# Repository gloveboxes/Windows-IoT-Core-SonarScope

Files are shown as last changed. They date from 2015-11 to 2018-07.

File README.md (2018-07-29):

# Windows-IoT-Core-SonarScope

Original Project Inspiration [Windows 10 IoT Core: UltraSonic Distance Mapper](https://microsoft.hackster.io/en-US/AnuragVasanwala/windows-10-iot-core-ultrasonic-distance-mapper-d94d63)

This project has had a lot of love, optimisation and polish espically around XAML with special fade effects and object clean up.

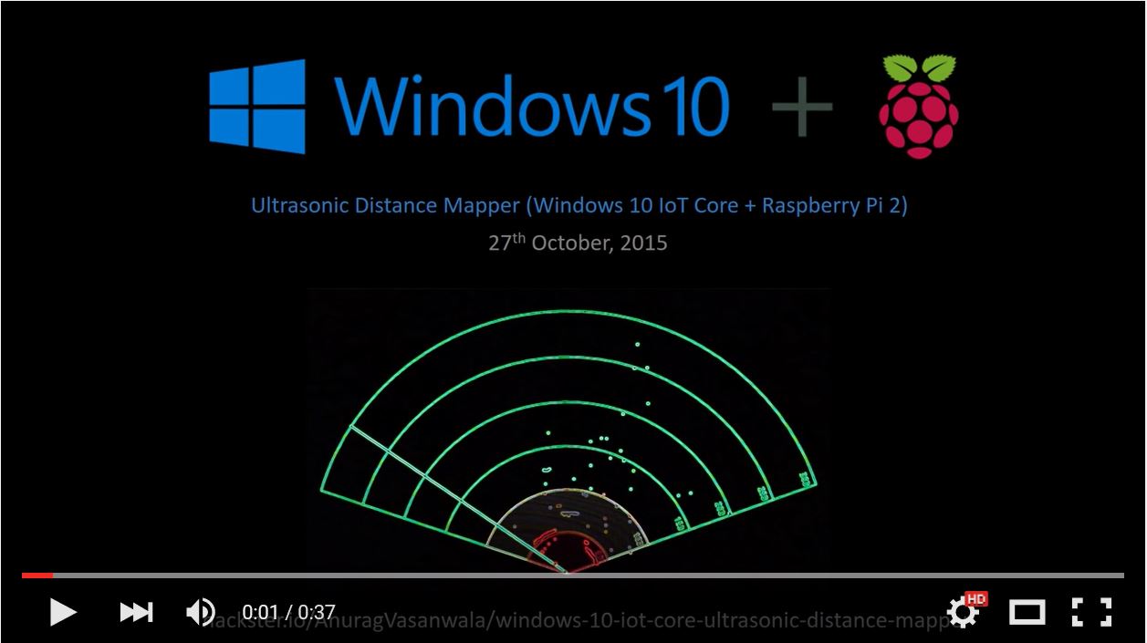
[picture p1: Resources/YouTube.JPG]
Youtube (https://youtu.be/GKRDX3nHlks)


<iframe width="420" height="315" src="https://www.youtube.com/embed/GKRDX3nHlks" frameborder="0" allowfullscreen></iframe>

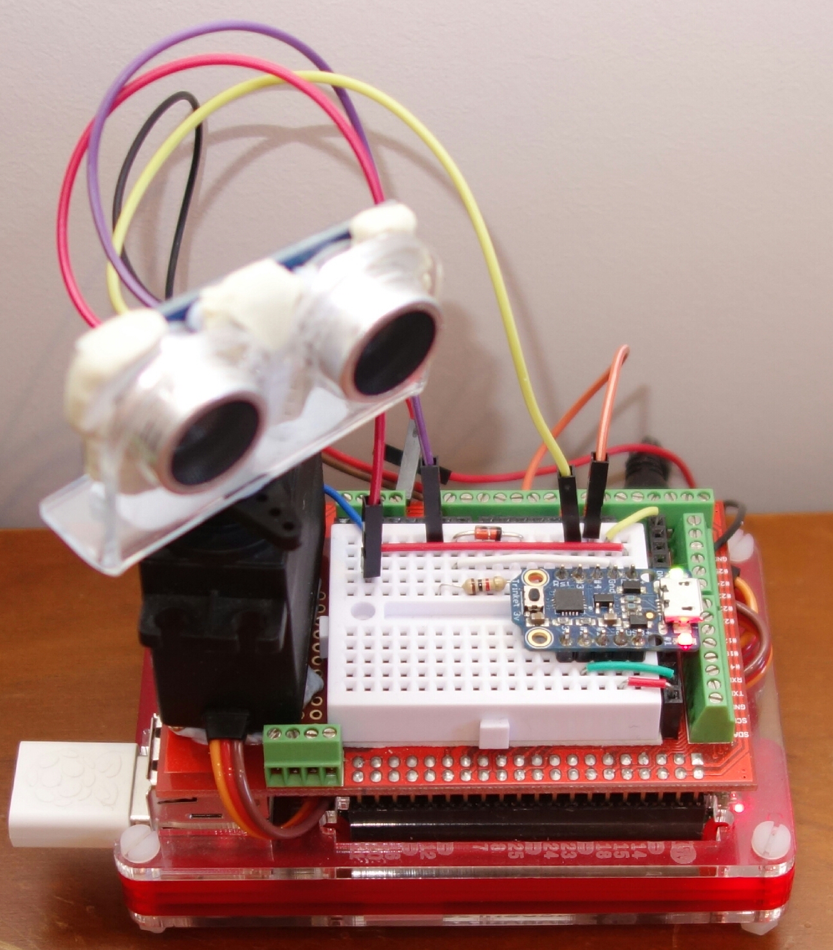
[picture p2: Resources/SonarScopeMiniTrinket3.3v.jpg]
Sonar Scope


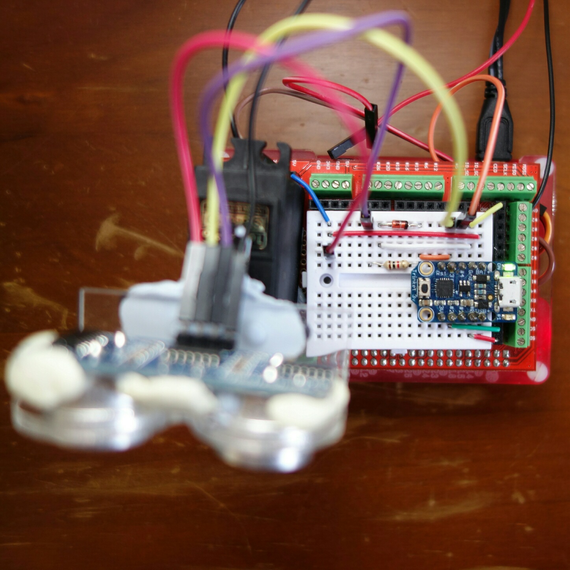
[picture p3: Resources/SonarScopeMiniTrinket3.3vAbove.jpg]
Sonar Scope


This project drives the servo over I2C bus from Windows IoT Core to Trinket Mini 3.3V Arduino board.

[Trinket Mini 3.3V](https://www.adafruit.com/products/1500) as it operates at the same voltage as the Raspberry Pi no logic level shifter required.

## Parts List

1. Raspberry Pi 2 or 3
2. [Adafruit Trinket - Mini Microcontroller - 3.3V Logic - MicroUSB](https://www.adafruit.com/products/1500)
3. [Zenor Diode 3.3v 1N4728A](http://au.rs-online.com/web/p/zener-diodes/8050034/)
4. 1K ohm resistor
5. 1 x Servo. I used a [Tower Pro SG-5010](https://www.adafruit.com/product/155)
6. HC-SR04 ultrasonic sensor. Widely avaiable sensor
7. [Servo Power Connector](https://www.jaycar.com.au/2-1mm-dc-socket-with-screw-terminals/p/PA3713)

## Powering the Servo

Ideally you should power the servo from its own separate power supply. However, given the servo is under very light load and if you are careful not to stall the servo you will likely get away with powering the servo from the 5v pin on the Raspberry Pi.

### Notes

1. A lightly loaded servo will draw around 200 milliamps
2. [Max current that can be supplied by 5V pin](http://raspberrypi.stackexchange.com/questions/42630/is-there-a-max-current-that-can-be-supplied-when-powering-the-pi-from-the-pins)

## Wiring

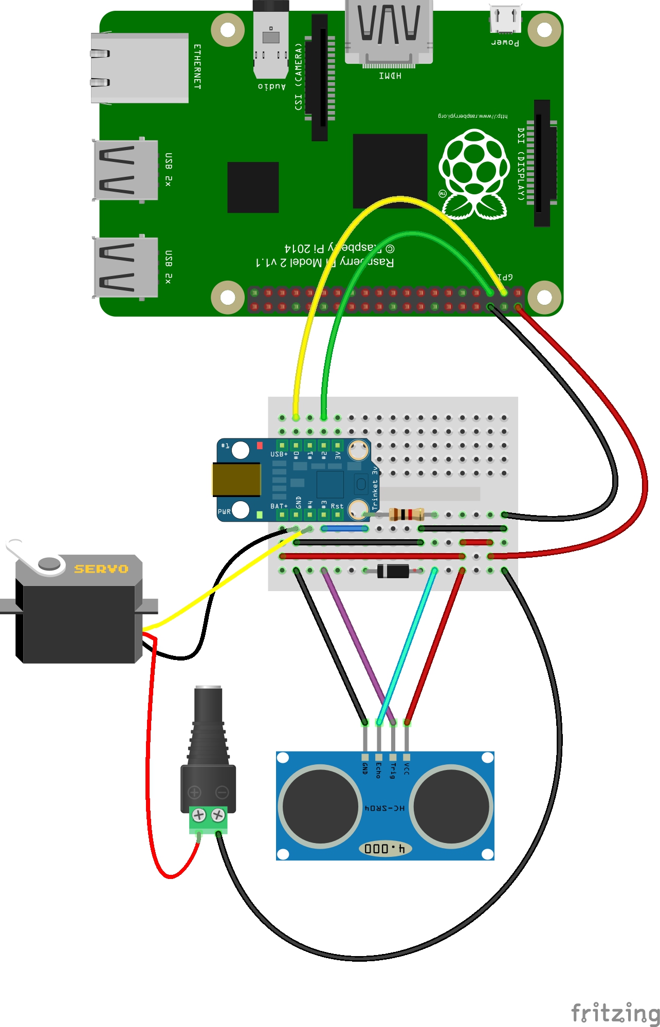
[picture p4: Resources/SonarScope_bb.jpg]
layout


## Alternate wiring for ATtiny85

I ended up swapping out the Adafruit Trinket for a ATtiny85 microcontroller. It's wired up as follows. I used an Arduino Uno to program the ATtiny85 as per these [instructions](https://www.instructables.com/id/Program-an-ATtiny-with-Arduino/). Worked very well and very fast.

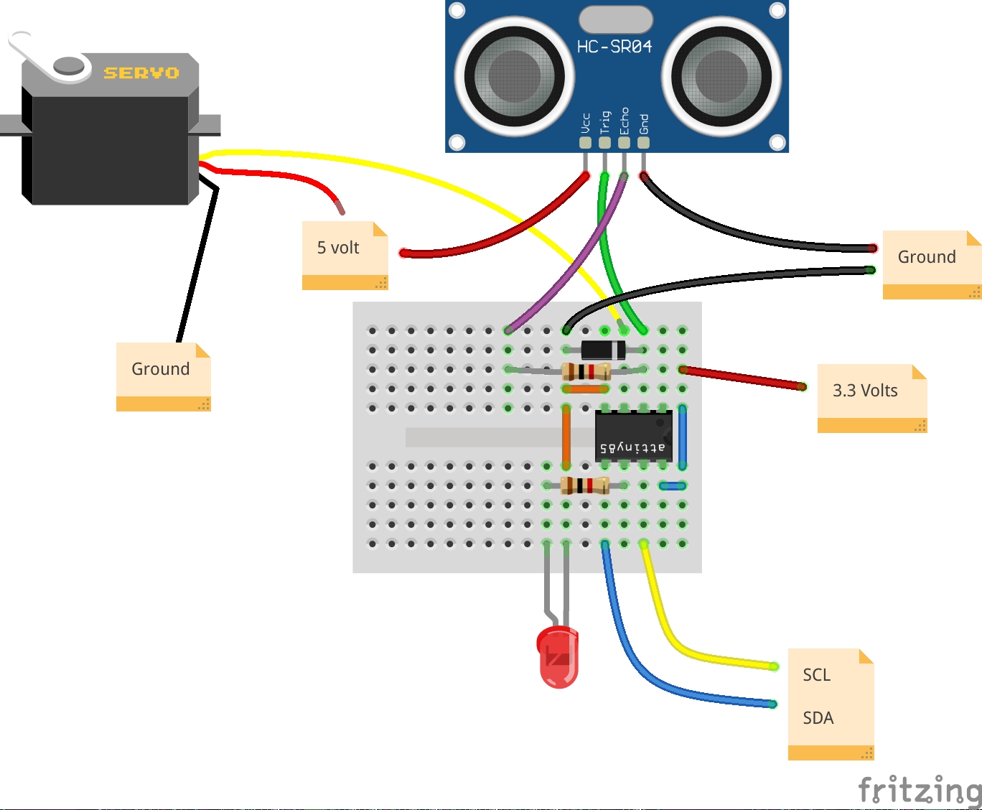
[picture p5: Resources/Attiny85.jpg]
ATtiny85


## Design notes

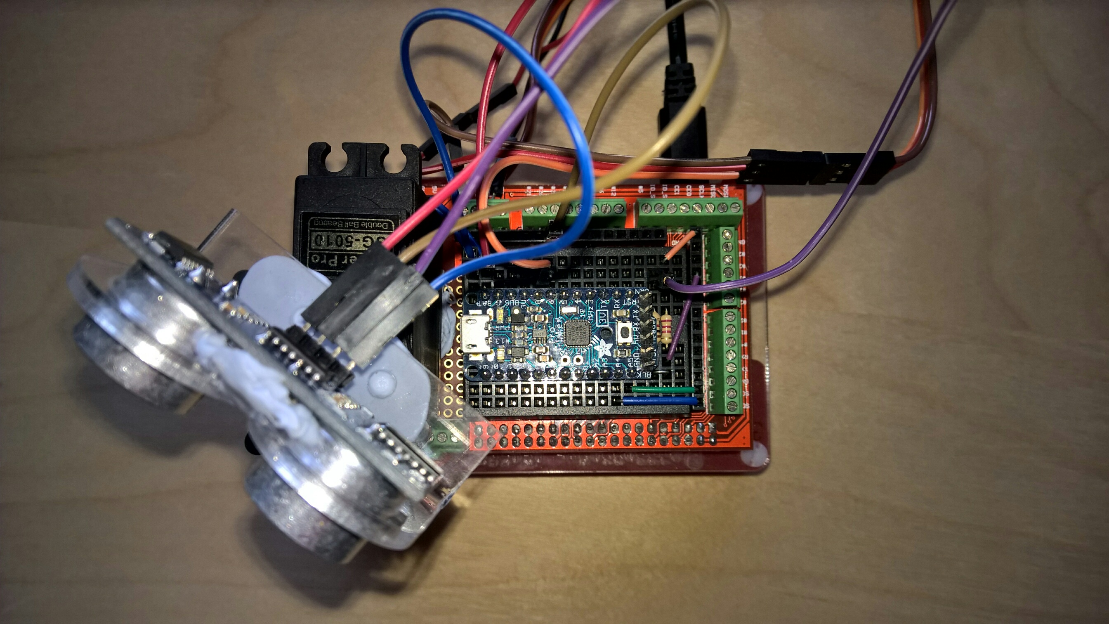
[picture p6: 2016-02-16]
Resources/SonarScope.jpg

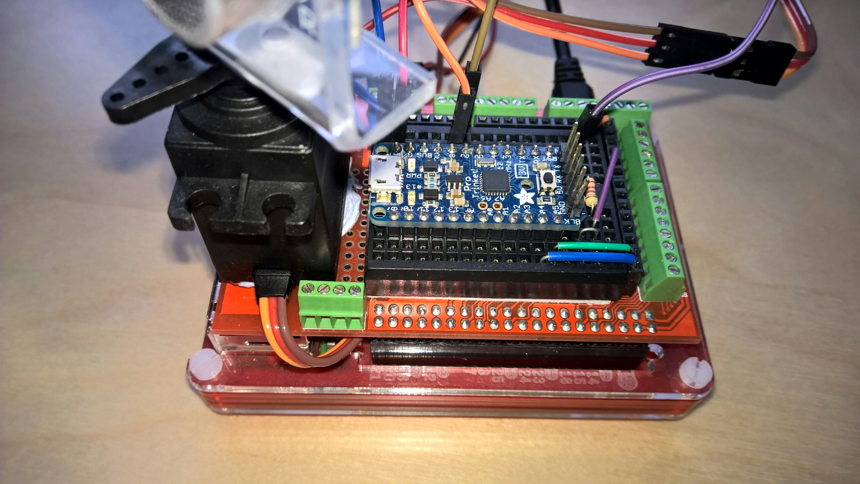
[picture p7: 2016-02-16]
Resources/SonarScopeArduino.jpg

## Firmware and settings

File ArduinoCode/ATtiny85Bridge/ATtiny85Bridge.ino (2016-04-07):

/*******************************************************************

  PROJECT OWNER: Dave Glover | dglover@microsoft.com | @dglover

  The MIT License (MIT)
  
  Copyright (c) 2015 Microsoft Corporation
  
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

  CREATED: Mar 2016

  SUMMARY: Display a sweeping radar image of objects detected by a servo mounted HC-SR04 Ultrasonic Range senor.

  ACKNOWLEDGMENTS: Project inspired by Windows 10 IoT Core: UltraSonic Distance Mapper
  https://microsoft.hackster.io/en-US/AnuragVasanwala/windows-10-iot-core-ultrasonic-distance-mapper-d94d63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

  PLATFORM: Raspberry Pi 2 running Windows 10 IoT Core

  1 x Raspberry Pi 2 running WIndows 10 IoT Core
  1 x Trinket 3.3V https://www.adafruit.com/products/1500
  1 x Servo, this sample uses a Tower Pro SG-5010 with 140 degree sweep
  1 x 1k resistor
  1 x 3.3 Zener Diode (see level shifter strategies - http://jamesreubenknowles.com/level-shifting-stragety-experments-1741)
  1 x mini breadboard
  1 x some jumper wires

  LIBRARIES: Though probably not best practice, all libraries are included in the project for longevity, versioning and simplicity reasons. See Required Libraries.
  
  REQUIRED LIBRARIES: Install Arduino Libraries from Sketch -> Include Library -> Manage Libraries
  - Adafruit SoftServo

  Download and install :-
  
  - TinyWireS (https://github.com/rambo/TinyWire)
  - TinyNewPing (https://github.com/Tony607/TinyNewPing)

*********************************************************************/

#include "Adafruit_SoftServo.h"  // SoftwareServo (works on non PWM pins)
#include "TinyWireS.h"           // wrapper class for I2C slave routines
#include "TinyNewPing.h"         // NewPing library modified for ATtiny


#define I2C_ADDRESS 0x40          //I2C Slave Address

#define SERVOPIN 4                // Servo control line (orange) on Trinket Pin
#define SERVO_MAX_DEGREES 140     // This sample uses Tower Pro SG-5010 with 140 degree sweep

#define RANGE_SENSOR_PIN  3       // Sensor 1 is connected to PB3
#define MAX_DISTANCE 250 // Maximum distance we want to ping for (in centimeters). Maximum sensor distance is rated at 400-500cm.

#define LEDPIN 1

byte i2cDataBuffer[6]; // i2c recieve data buffer

int lastServoPosition = 1000; // some random large number than the servo max degrees to trigger initial sensor measurement

bool ServoInitialised = false;
bool deferServoRefresh = false;  // minimise conflicts with event based servo refresh

byte Distance; // result from ultrasonic range sensor - limited to 8 bits 255 centimeters

Adafruit_SoftServo myServo;
NewPing SensorOne (RANGE_SENSOR_PIN, RANGE_SENSOR_PIN, MAX_DISTANCE);       // Define the Sensor - yes, using same pin for trigger and echo


enum ArduinoCmd : byte
{
    ServoMovePosition = (byte)'M'           //set Servo position
};

ArduinoCmd cmd;
unsigned short cmdIndex = 0; // worker variable

   
void setup() {
  // Set up the interrupt that will refresh the servo for us automagically
  OCR0A = 0xAF;            // any number is OK
  TIMSK |= _BV(OCIE0A);    // Turn on the compare interrupt (below!)

  pinMode(LEDPIN, OUTPUT);

  TinyWireS.begin(I2C_ADDRESS);      // init I2C Slave mode
  TinyWireS.onReceive(i2CReceived);   // register the onReceive() callback function
  TinyWireS.onRequest(requestEvent);         // When requested, call function transmit()

}

void loop()  {
  if (lastServoPosition != cmdIndex) {
      deferServoRefresh = true;      
      digitalWrite(LEDPIN, HIGH);   // turn the LED on (HIGH is the voltage level)
      
      Distance = SensorOne.ping_cm();        // Get distance in cm. Could be changed to 

      lastServoPosition = cmdIndex;
      digitalWrite(LEDPIN, LOW);   // turn the LED on (HIGH is the voltage level)      
      deferServoRefresh = false;
  }
  
  TinyWireS_stop_check(); 
}


/* This function will automatically be called when RPi2 sends data to this I2C slave */
void i2CReceived(uint8_t  NumberOfBytes)
{
  /***************
  I2C data packet format
  byte 0 = Command
  byte 1-2 = Command index
  byte 3-5 = arbitory based on scenario - could be red, green, blue for a neopixel or set neopixel string size etc or pin numnders for neopixel or servo
  ***************/

  deferServoRefresh = true;  
  
  if (NumberOfBytes != 6) {
    for (int b = 0; b < NumberOfBytes; b++){
      TinyWireS.receive();
    }
    return;
  }
  
  for (int b = 0; b < 6; b++){
    i2cDataBuffer[b] = TinyWireS.receive();
  }

  cmd = (ArduinoCmd)i2cDataBuffer[0];  
  cmdIndex = (i2cDataBuffer[1] << 8) + i2cDataBuffer[2];  // build unsigned short 16 bit index.

  switch(cmd){    
    case ServoMovePosition:
      if (!ServoInitialised) {
//          myServo1.attach(i2cDataBuffer[3]); 
          myServo.attach(SERVOPIN); 
          ServoInitialised = true;
      }
      setServoPosition(cmdIndex);
      break;
  }

  deferServoRefresh = false;
}

void setServoPosition(int degrees){
  if (degrees < 0) { degrees = 0; }
  if (degrees > SERVO_MAX_DEGREES) {degrees = SERVO_MAX_DEGREES; }
  int pos = map(degrees, 0, SERVO_MAX_DEGREES, 0, 255);
  myServo.write(pos);      
}

void requestEvent()
{
  deferServoRefresh = true;
  TinyWireS.send(Distance);                 // Send last recorded distance for current sensor
  deferServoRefresh = false;
}


// We'll take advantage of the built in millis() timer that goes off
// to keep track of time, and refresh the servo every 20 milliseconds
volatile uint8_t counter = 0;
SIGNAL(TIMER0_COMPA_vect) {
  counter += 2;           // this gets called every 2 milliseconds
  if (!deferServoRefresh && counter >= 40) {    // every 40 milliseconds, refresh the servos!
    counter = 0;
    myServo.refresh();
  }
}

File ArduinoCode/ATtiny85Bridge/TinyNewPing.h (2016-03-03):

//TinyNewPing Library is the NewPing library modified for use with an ATtiny


// ---------------------------------------------------------------------------
// NewPing Library - v1.5 - 08/15/2012
//
// AUTHOR/LICENSE:
// Created by Tim Eckel - teckel@leethost.com
// Copyright 2012 License: GNU GPL v3 http://www.gnu.org/licenses/gpl-3.0.html
//
// LINKS:
// Project home: http://code.google.com/p/arduino-new-ping/
// Blog: http://arduino.cc/forum/index.php/topic,106043.0.html
//
// DISCLAIMER:
// This software is furnished "as is", without technical support, and with no
// warranty, express or implied, as to its usefulness for any purpose.
//
// BACKGROUND:
// When I first received an ultrasonic sensor I was not happy with how poorly
// it worked. Quickly I realized the problem wasn't the sensor, it was the
// available ping and ultrasonic libraries causing the problem. The NewPing
// library totally fixes these problems, adds many new features, and breaths
// new life into these very affordable distance sensors.
//
// FEATURES:
// * Works with many different ultrasonic sensor models: SR04, SRF05, SRF06, DYP-ME007 & Parallax PING)))™.
// * Interface with all but the SRF06 sensor using only one Arduino pin.
// * Doesn't lag for a full second if no ping/echo is received.
// * Ping sensors consistently and reliably at up to 30 times per second.
// * Timer interrupt method for event-driven sketches.
// * Built-in digital filter method ping_median() for easy error correction.
// * Uses port registers for a faster pin interface and smaller code size.
// * Allows you to set a maximum distance where pings beyond that distance are read as no ping "clear".
// * Ease of using multiple sensors (example sketch with 15 sensors).
// * More accurate distance calculation (cm, inches & uS).
// * Doesn't use pulseIn, which is slow and gives incorrect results with some ultrasonic sensor models.
// * Actively developed with features being added and bugs/issues addressed.
//
// CONSTRUCTOR:
//   NewPing sonar(trigger_pin, echo_pin [, max_cm_distance])
//     trigger_pin & echo_pin - Arduino pins connected to sensor trigger and echo.
//       NOTE: To use the same Arduino pin for trigger and echo, specify the same pin for both values.
//     max_cm_distance - [Optional] Maximum distance you wish to sense. Default=500cm.
//
// SYNTAX:
//   sonar.ping() - Send a ping and get the echo time (in microseconds) as a result.
//   sonar.ping_in() - Send a ping and get the distance in whole inches.
//   sonar.ping_cm() - Send a ping and get the distance in whole centimeters.
//   sonar.ping_median(iterations) - Do multiple pings (default=5), discard out of range pings and return median in microseconds.
//   sonar.convert_in(echoTime) - Convert echoTime from microseconds to inches (rounds to nearest inch).
//   sonar.convert_cm(echoTime) - Convert echoTime from microseconds to centimeters (rounds to nearest cm).
//   sonar.ping_timer(function) - Send a ping and call function to test if ping is complete.
//   sonar.check_timer() - Check if ping has returned within the set distance limit.
//   NewPing::timer_us(frequency, function) - Call function every frequency microseconds.
//   NewPing::timer_ms(frequency, function) - Call function every frequency milliseconds.
//   NewPing::timer_stop() - Stop the timer.
//
// HISTORY:
// 08/15/2012 v1.5 - Added ping_median() method which does a user specified
//   number of pings (default=5) and returns the median ping in microseconds
//   (out of range pings ignored). This is a very effective digital filter.
//   Optimized for smaller compiled size (even smaller than skteches that
//   don't use a library).
//
// 07/14/2012 v1.4 - Added support for the Parallax PING)))™ sensor. Interface
//   with all but the SRF06 sensor using only one Arduino pin. You can also
//   interface with the SRF06 using one pin if you install a 0.1uf capacitor
//   on the trigger and echo pins of the sensor then tie the trigger pin to
//   the Arduino pin (doesn't work with Teensy). To use the same Arduino pin
//   for trigger and echo, specify the same pin for both values. Various bug
//   fixes.
//
// 06/08/2012 v1.3 - Big feature addition, event-driven ping! Uses Timer2
//   interrupt, so be mindful of PWM or timing conflicts messing with Timer2
//   may cause (namely PWM on pins 3 & 11 on Arduino, PWM on pins 9 and 10 on
//   Mega, and Tone library). Simple to use timer interrupt functions you can
//   use in your sketches totaly unrelated to ultrasonic sensors (don't use if
//   you're also using NewPing's ping_timer because both use Timer2 interrupts).
//   Loop counting ping method deleted in favor of timing ping method after
//   inconsistant results kept surfacing with the loop timing ping method.
//   Conversion to cm and inches now rounds to the nearest cm or inch. Code
//   optimized to save program space and fixed a couple minor bugs here and
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

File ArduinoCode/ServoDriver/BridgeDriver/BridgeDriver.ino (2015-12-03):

#include <Wire.h>
#include <Adafruit_NeoPixel.h>
#include <Servo.h> 

#define MyAddress 0x40

Adafruit_NeoPixel pixels;
unsigned short numPixels = 0;  // How many NeoPixels are attached to the Arduino?


/* Create object for servo motor */
Servo MyServo;
bool ServoInitialised = false;
//byte oldPosition = 0;
//int newPosition = 70;

enum ArduinoCmd : byte
{
    InitialiseNeoPixel = (byte)'I',     //Initialize NeoPixel
    SetNeoPixel = (byte)'P',               //set a NeoPixel pixel value
    DisplayNeoPixel = (byte)'D',         //render NeoPixel pixels to the display
    ServoMovePosition = (byte)'M'           //set Servo position
};

ArduinoCmd cmd;

void setup()
{

//  Serial.begin(115200);
//  while (!Serial) {
//    ; // wait for serial port to connect. Needed for Leonardo only
//  }
  

  pinMode(13, OUTPUT);

  Wire.begin(MyAddress);    /* Initialize I2C Slave & assign call-back function 'onReceive' */
  Wire.onReceive(I2CReceived);
  Wire.onRequest(requestEvent); //Zgłaszane przy żądaniu odczytu (nadawca: Read)
}


void loop() {
// if (ServoInitialised && newPosition != oldPosition) {
//    digitalWrite(13, HIGH);   // turn the LED on (HIGH is the voltage level) 
//
//    oldPosition = newPosition;
//    MyServo.write(oldPosition);  // Move servo to specified the position //
//
//    digitalWrite(13, LOW);
//  }
}

void requestEvent() {
//    Serial.println("RESPONSE");
//    Wire.write(arr,2);
}

/* This function will automatically be called when RPi2 sends data to this I2C slave */
void I2CReceived(int NumberOfBytes)
{
  int temp;

//data format
//byte 0 = Command
//byte 1-2 = index
//byte 3-5 = arbitory could be red, green, blue for a neopixel or set neopixel string size etc or pin numnders for neopixel or servo
  
  byte data[6];
  unsigned short index = 0;
  
  if (NumberOfBytes != 6) {
    for (int b = 0; b < NumberOfBytes; b++){
      Wire.read();
    }
    return;
  }
  
  for (int b = 0; b < 6; b++){
    data[b] = Wire.read();
  }


  cmd = (ArduinoCmd)data[0];  // S = Set pixel, // R = Render Frame
  index = (data[1] << 8) + data[2];  // build unsigned short 16 bit index

  switch(cmd){
    case InitialiseNeoPixel:  // Initialise
      if (numPixels > 0 || index > 512) { return; }
      numPixels = index;
      pixels = Adafruit_NeoPixel(numPixels, data[3], NEO_GRB + NEO_KHZ800);
      pixels.begin(); // This initializes the NeoPixel library.
      break;
      
    case DisplayNeoPixel:  // display neopixel
      if (numPixels == 0) {
        if (index > 512) { return; }
        numPixels = index;
        pixels = Adafruit_NeoPixel(numPixels, data[3], NEO_GRB + NEO_KHZ800);
        pixels.begin(); // This initializes the NeoPixel library.
      }
      else {
        digitalWrite(13, HIGH);
        pixels.show(); // This sends the updated pixel color to the hardware.
        digitalWrite(13, LOW);
      }
      break;
      
    case SetNeoPixel:  // Set Pixel
      if (numPixels == 0 || index > numPixels) { return; }
      pixels.setPixelColor(index, pixels.Color(data[3],data[4],data[5]));
      break;
    
    case ServoMovePosition:
      if (!ServoInitialised) {
          MyServo.attach(data[3]); 
          ServoInitialised = true;
      }
      MyServo.write(index);
      break;
  }
}

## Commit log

2015-11-22 Name change and added Arduino solution folder
2015-11-23 update to pins used for sonar
2015-11-24 Potential fix for I2C sync issues with Arduino. Changed I2C mode to standard In Arduino - more the servo command to the main loop.
    [ServoDriver.ino]
2015-11-24 refactored arduino loop
2015-11-24 Arduino code visual reformat
2015-11-24 removed i2c reset on i2c write exception and I think causing restart issues...
2015-11-24 added more robust I2C comms error detection both on Arduino and Windows IoT Core app
    [ServoDriver.ino]
2015-11-25 updated to use the ultra sonic distance sensor in glovebox.iot.devices. Changed stepping to 2 degrees, up from 1
2015-11-25 Updated to use new max distance constructor on hcsr04 distance sensor
2015-12-01 updated servo i2c to fast mode
2015-12-02 Migrated to Arduino Bridge library
2015-12-03 adding arduino BridgeDriver.ino
2015-12-03 remove old arduino driver
2016-03-03 Added Trinket 3.3V ATtiny85 Support
2016-04-07 Updated for use with a Adafruit Trinket
    [SonarScope.fzz]
2017-01-02 Layout Image Mini Trinket 3.3v
2018-05-01 Added ATTiny85Bridge Arduino Code
